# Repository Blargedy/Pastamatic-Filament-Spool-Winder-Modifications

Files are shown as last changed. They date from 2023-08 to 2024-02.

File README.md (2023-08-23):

# Pastamatic Filament Spool Winder Modifications
Modifications to [GekoPrime's](https://www.printables.com/@GekoPrime) winder to better meet my use-cases. Features braces for rigidity and alignment, as well as support for spooling from Polymaker's 5kg spools.

The friction on the leadscrew tooth was enough to have the leadscrew block jump up and pull the whole machine up with it. I created a brace that adds more stiffness than just the crossbars, and added a clamping tab for good measure. 


The source cradle had too much skew play for my liking so I created a brace to match the target brace above.  


I wanted to be able to respool from Polymaker's 5kg spools, so I modified the source brace to fit the large spool. However the height of the 5kg idlers was enough that the single flat brace I used for the 3kg spools didn't suffice. I added collars that bolt together for optimal stiffness. 




## Parts to Print
* import `Full_Set_of_Parts.3mf` and you will get all the parts you need.
* If you don't have a 300mm or greater build plate print the `1x_source_brace_for_5kg_spools_small_bed.stl` instead of the regular one.
  
The wiper mounts were, in my experience, completely useless and only got in the way. You may try them yourself but imo they're a waste of time and filament. I also found the spindle_clip to kinda suck, but ymmv.

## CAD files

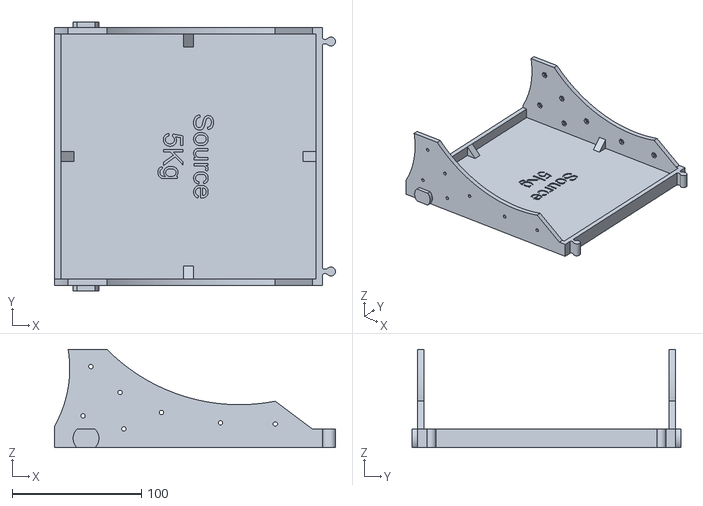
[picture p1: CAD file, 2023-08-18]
STLs/1x_source_brace_for_5kg_spools_small_bed.stl
217.6 x 208.0 x 75.9

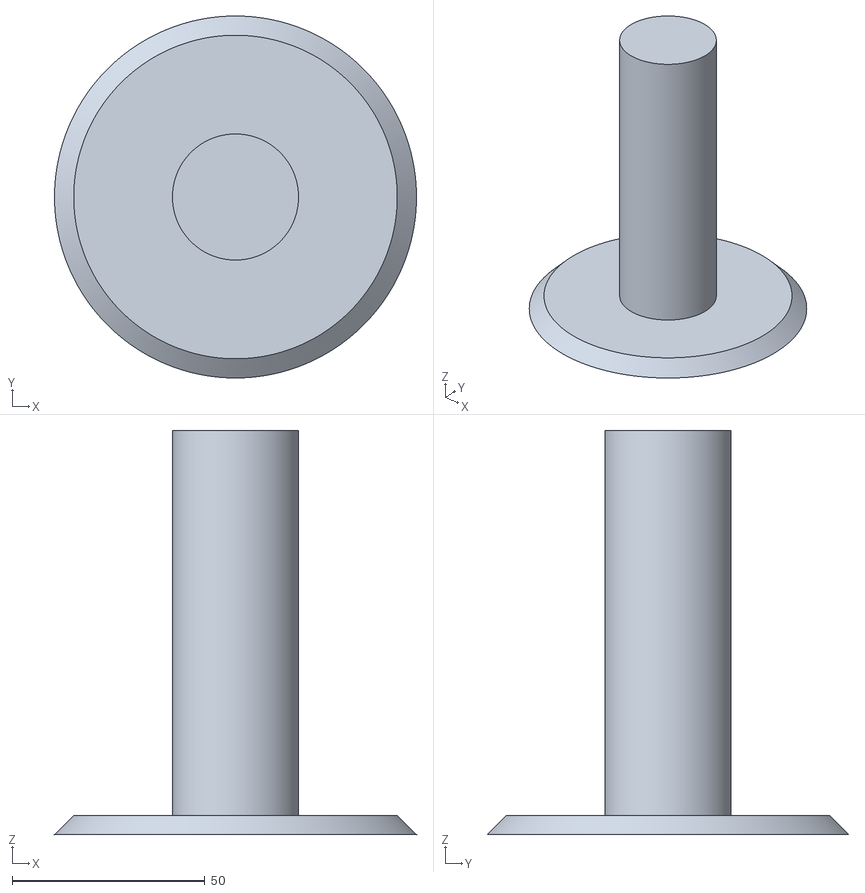
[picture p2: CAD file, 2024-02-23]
STLs/Options/spacer_storage_pole.stl
94.0 x 94.0 x 105.0

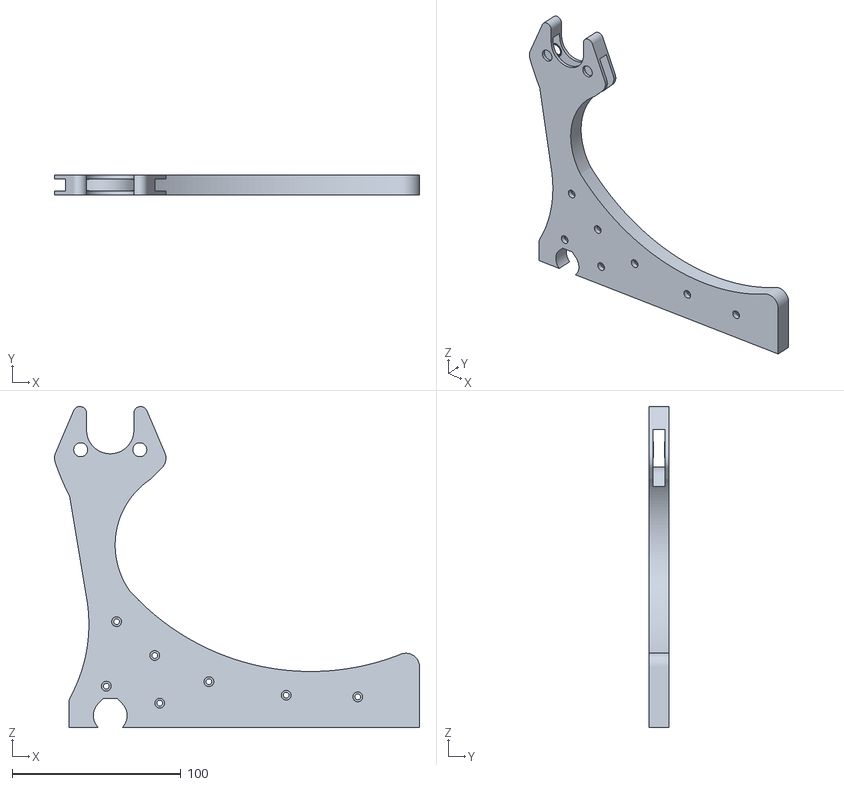
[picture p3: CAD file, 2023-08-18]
STLs/1x_source_cradle_for_5kg_spools.stl
216.1 x 11.6 x 190.0

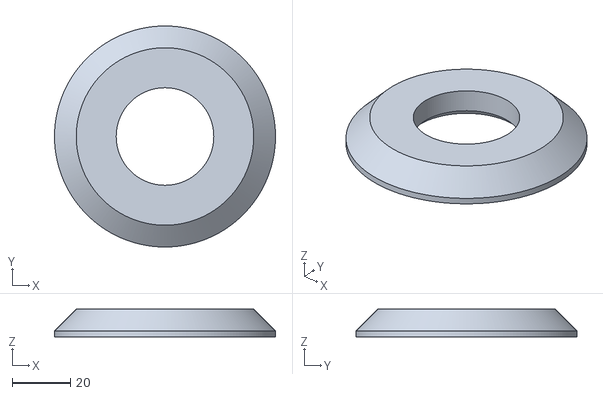
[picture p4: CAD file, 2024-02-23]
STLs/Options/spindle_spacer_XL.stl
76.0 x 76.0 x 9.50

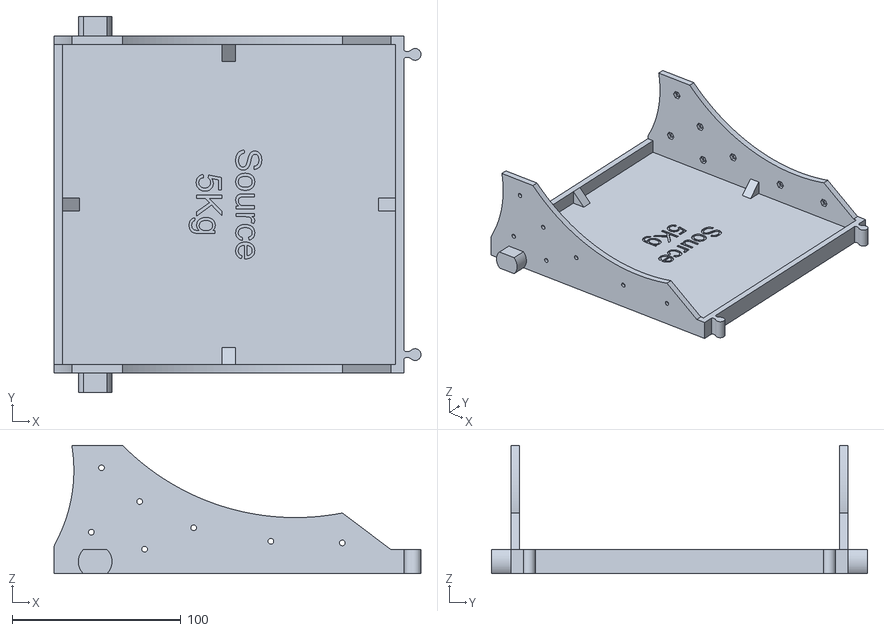
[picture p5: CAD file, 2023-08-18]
STLs/1x_source_brace_for_5kg_spools.stl
217.6 x 223.2 x 75.9

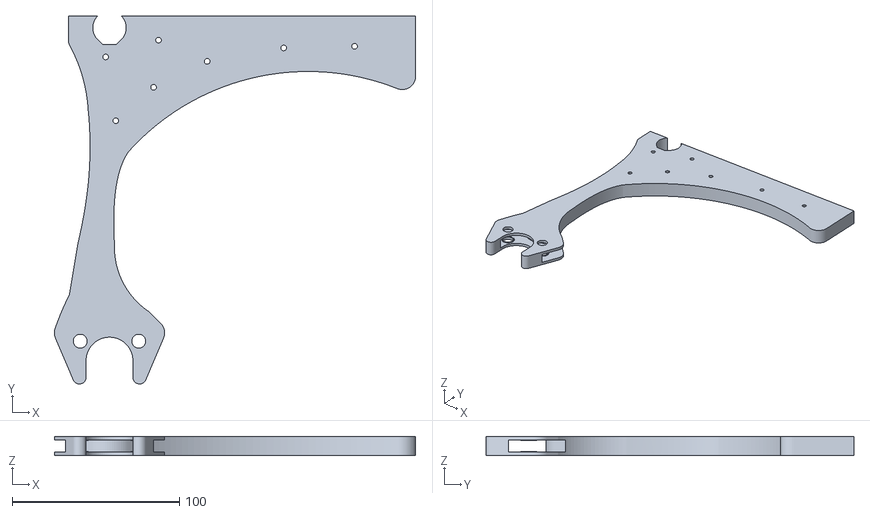
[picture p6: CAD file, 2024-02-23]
STLs/Options/1x_source_cradle_for_5kg_spools_longboi.stl
216.1 x 220.0 x 11.6

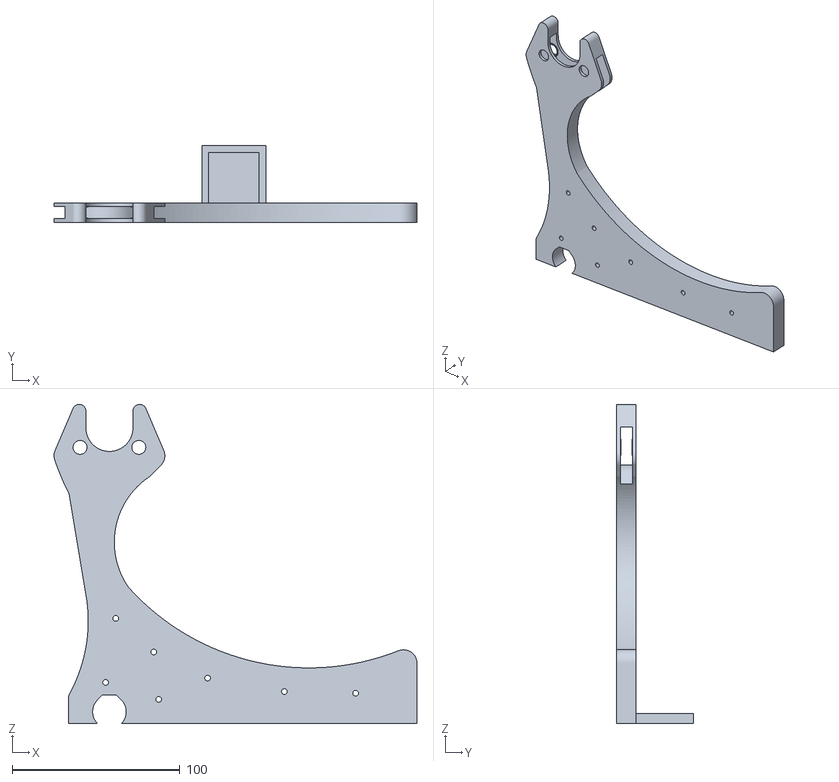
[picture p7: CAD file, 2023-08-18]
STLs/1x_source_cradle_for_5kg_spools_clamp.stl
216.1 x 45.6 x 190.0

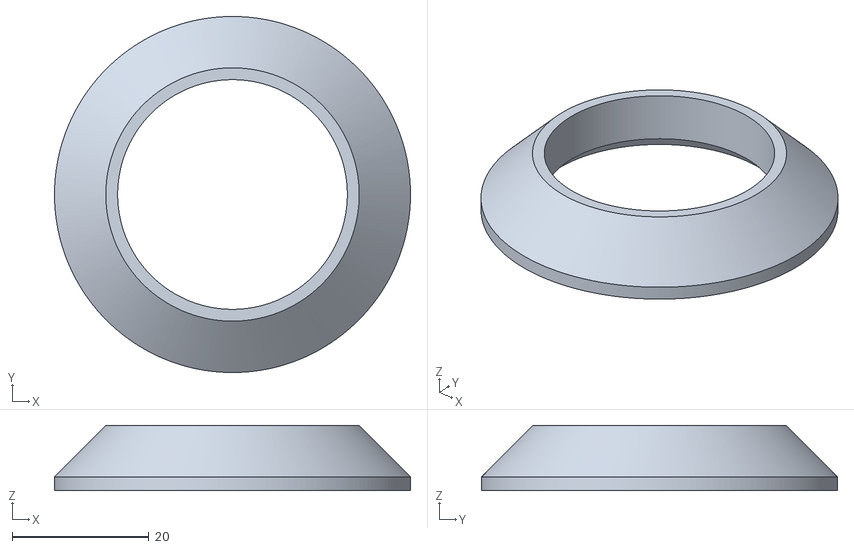
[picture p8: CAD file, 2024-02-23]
STLs/Options/spindle_spacer_S.stl
52.0 x 52.0 x 9.50

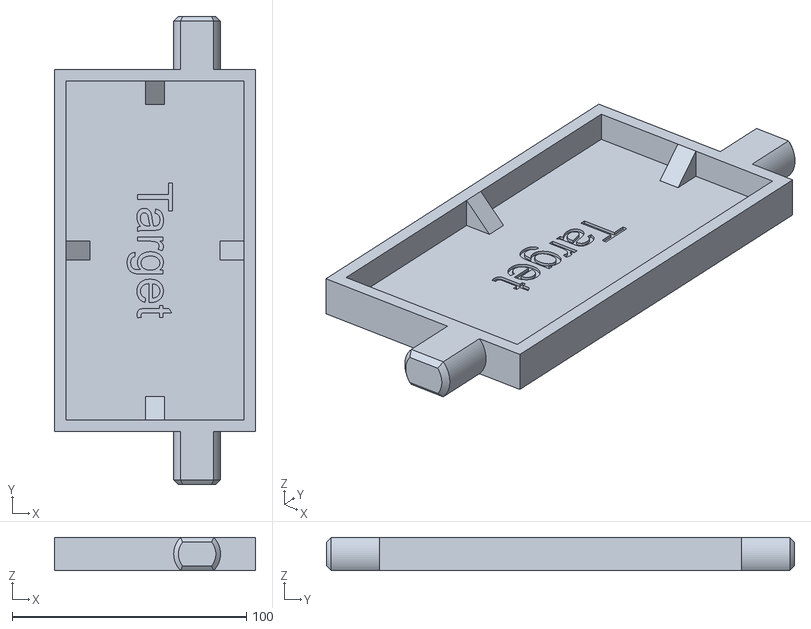
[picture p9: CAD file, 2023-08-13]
STLs/1x_target-side_brace.stl
86.0 x 200.0 x 14.1

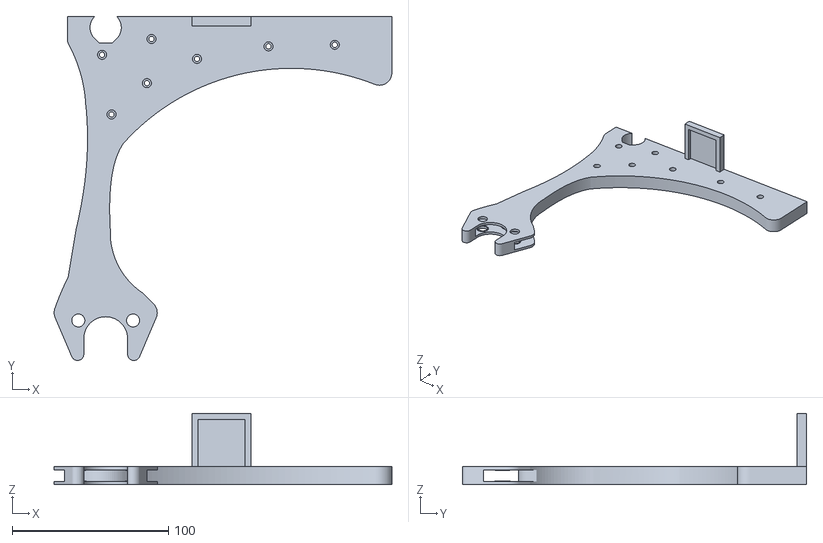
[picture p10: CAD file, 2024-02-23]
STLs/Options/1x_source_cradle_for_5kg_spools_clamp_longboi.stl
216.1 x 220.0 x 45.6

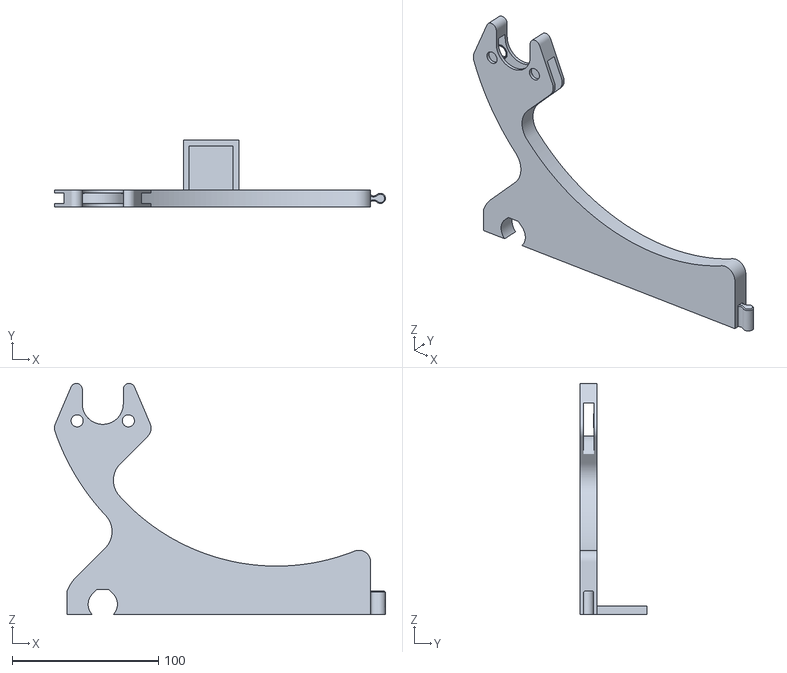
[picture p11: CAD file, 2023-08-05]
STLs/1x_source_cradle_clamp_tab.stl
226.2 x 45.6 x 158.0

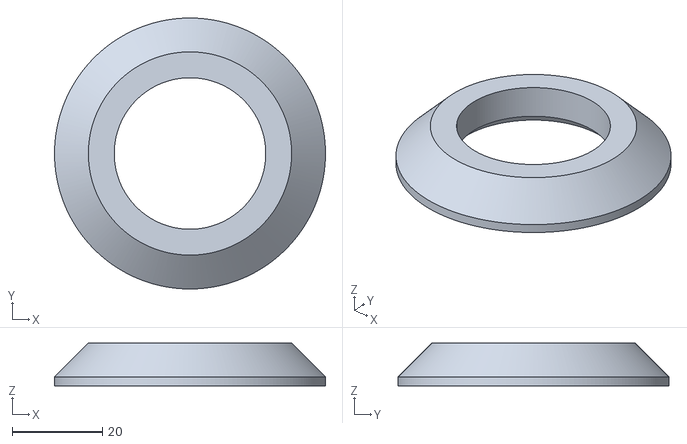
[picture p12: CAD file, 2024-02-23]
STLs/Options/spindle_spacer_M.stl
60.0 x 60.0 x 9.50

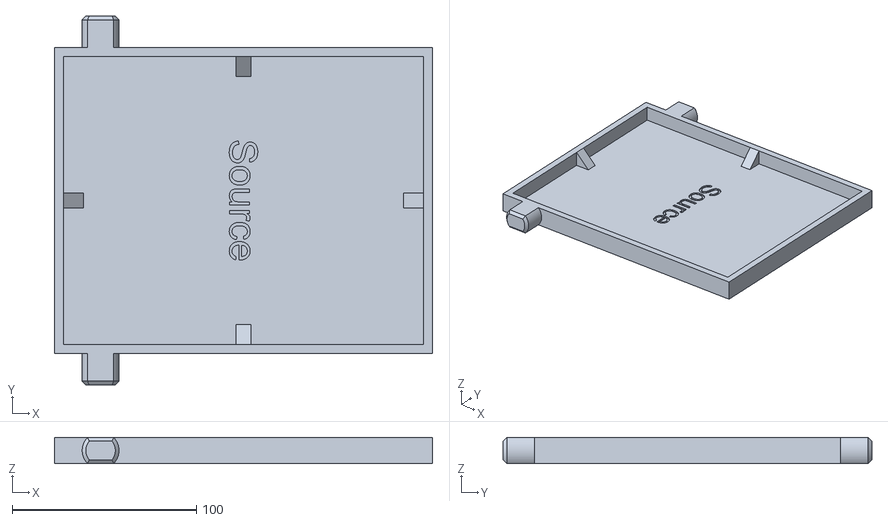
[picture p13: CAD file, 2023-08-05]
STLs/1x_source_brace.stl
205.0 x 200.0 x 14.1

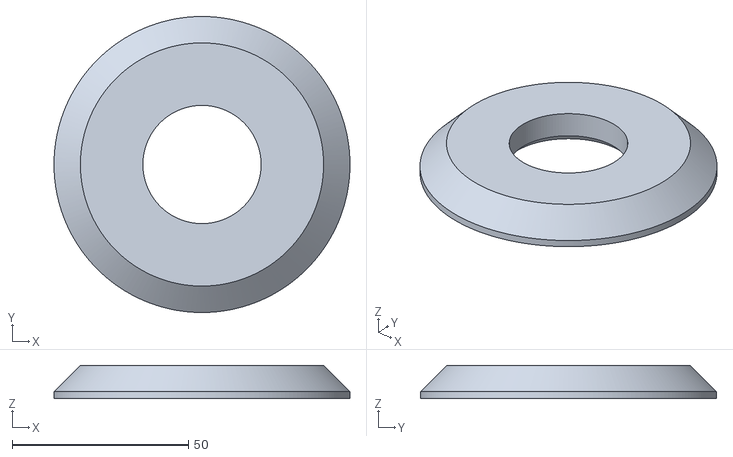
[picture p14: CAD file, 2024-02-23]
STLs/Options/spindle_spacer_XXL.stl
84.0 x 84.0 x 9.50

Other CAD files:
STLs/1x_driven_target_cradle_clamp_tab.stl
STLs/Options/spindle_spacer_L.stl
STLs/Options/spacer_storage_cap.stl
STLs/1x_leadscrew_block_lowered.stl

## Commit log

2023-08-05 untested first version
    [1x_driven_target_cradle_clamp_tab.stl, 1x_leadscrew_block_lowered.stl, 1x_source_brace.stl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]
2023-08-13 finalize 5kg cradle
    [1x_source_cradle_for_5kg_spools.stl, 1x_source_cradle_for_5kg_spools_clamp.stl, 1x_target-side_ brace.stl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]
2023-08-18 verified function of 5kg spool modifications
    [1x_source_brace_for_5kg_spools.stl, 1x_source_brace_for_5kg_spools_small_bed.stl, 1x_source_cradle_for_5kg_spools.stl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]
2023-08-23 added 3mf that contains all needed parts
    [1x_driven_target_cradle_clamp_tab.stl, 1x_leadscrew_block_lowered.stl, 1x_source_brace.stl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]
2024-02-23 added options for various spool sizes
    [1x_source_cradle_for_5kg_spools_clamp_longboi.stl, 1x_source_cradle_for_5kg_spools_longboi.stl, spacer_storage_cap.stl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]
